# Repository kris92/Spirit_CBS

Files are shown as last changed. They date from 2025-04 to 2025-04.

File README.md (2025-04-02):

<p align="center">
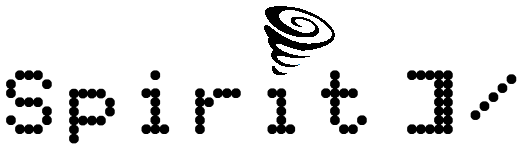
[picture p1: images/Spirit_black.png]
  
  </br>
  <font size="6">Pronounce <b>CBS</b> : <b>C</b><i>losed</i> <b>B</b><i>racket</i> <b>S</b><i>lash</i></font>
  </br>
  <font size="4">Work In Progress</font>
</p>

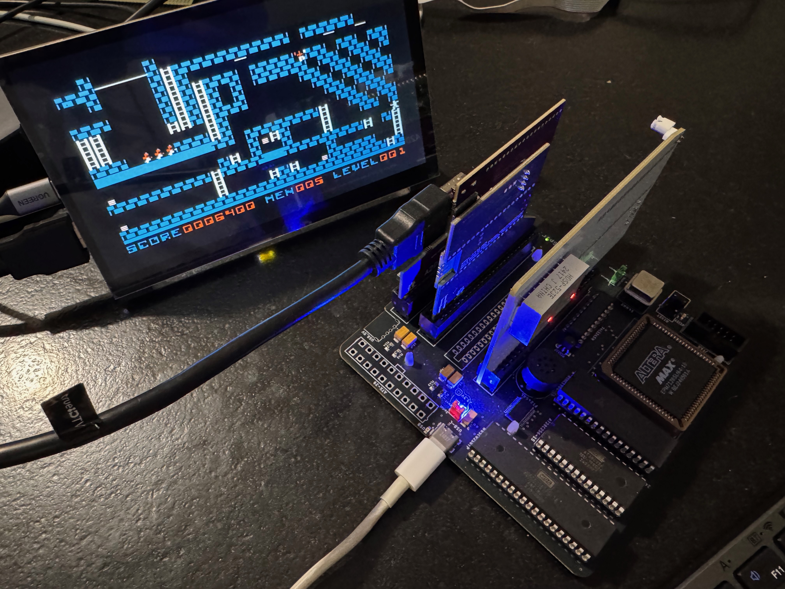
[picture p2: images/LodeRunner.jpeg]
LodeRunner


This is an attempt to build a computer somewhere in the middle of an Apple ][ and an Apple //e. So its name is Spirit ]/ (a computer with Apple II series in mind). Since the WAF (Wife Acceptance Factor) of the Apple // form factor (with disk drives and display) is somewhere near zero, I'm looking for something smaller. The first PCB iteration was half size of the System 2 with only a single slot. But one slot is really not enough.<br>
I build a serial USB probe that was really helpful for initial debuging with an interactive step mode. 
<p align="center">
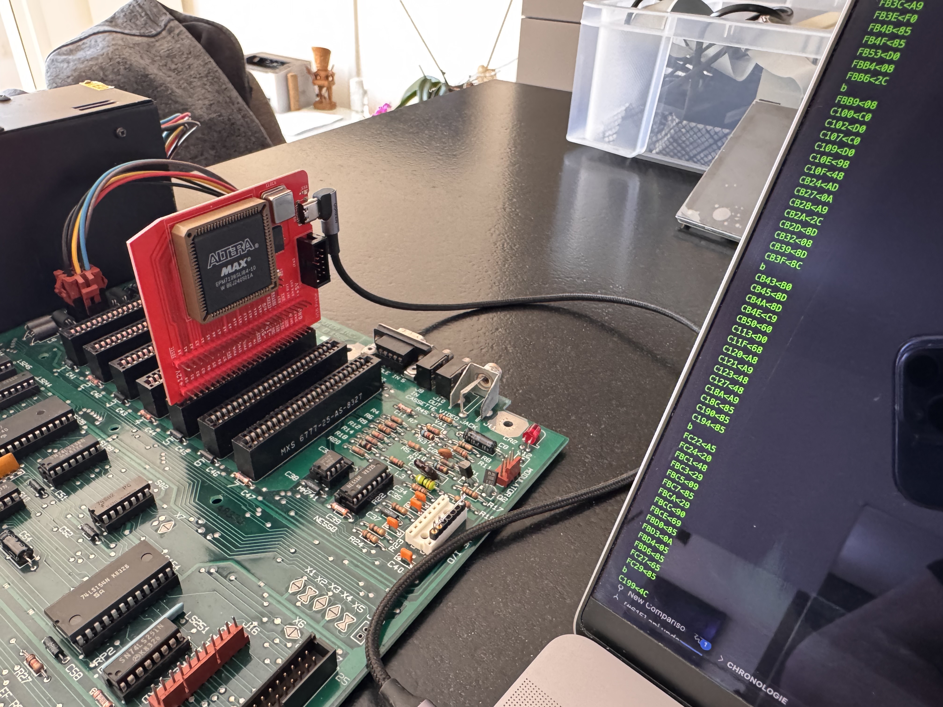
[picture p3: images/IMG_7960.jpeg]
  
  </br>
</p>

So my requirements were :

• Small (For example I choosed Pico ATX and single chips for SRAM(128K) and EEPROM).

• Compatibility with floppy drives (I ❤ how they are sounding).

• Slots. Some hardware Apple II projects exist, but I want floppies and the ability to use some of the cards from my drawers.

• Not necessary 100% compatible.

• Remove on board video to simplify design and HDMI is now possible.

• USB / RF Keyboard

• A2 Joystick

• SSC over USB (FT245) if I have enough space in the CPLD.

3 designs are planned :

• System 1 : 12cm x 12cm board for POC. 4 slots (3 + 1 since slot 0 is a ghost of slot 2 which I used for the keyboard)

• System 2 : 12cm x 14cm board with embeded USB keybpard support. 5 slots.

• System 3 : Apple //c form factor motherboard with //c keyboard support and A2DVI. 3 slots (small form factor. A2heaven like)

For this actual design, I tried to find the right balance between CPLD pins count, the fewest number of external chips and CPLD size for vhdl coding. So the actual result is not perfect but a quite good compromise in my own opinion.

Until now, Disk ][, A2Pico (SD Card), A2DVI and PRODOS-ROM cards were succesfully tested. Since native video generation is not implemented, some games may not working. I will study the possibility to emulate Blanking Softswitches and maybe vapor bits if I can find enough space in the CPLD.

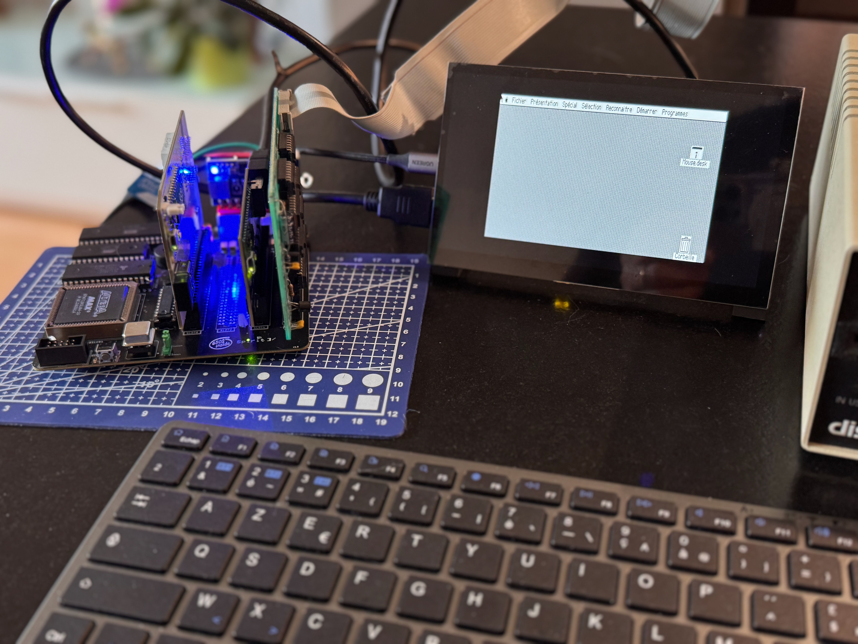
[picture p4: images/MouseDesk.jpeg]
MouseDesk loaded from a floppy


# Status
Full code for System 2 will be released as soon as a stable minimal system will be available.
| System | Date | Status |
| --- | --- | --- |
| <b>System 1</b> | 2025-03-01 | Finished.<br>Floppy, SDCard, USB Keyboard, A2DVI working.<br>Basic test of joystick interface.<br>Prodos 2.4.2 Ok.<br>Some games tested.<br>FastChip splash screen displayed then froze.<br> |
| <b>System 2</b> | 2025-03-31 | Waiting for first PCBs from JLCPCB : Motherboard, SmartPort, Disk ][, //c Keyboard interface.<br>//c keyboard RP2040 code ready. |
| <b>System 3</b> | 2025-03-31 | Initial PCB ordered for case integration test.<br>Riser card PCB ordered for slots. |

# Motherboard

The needed functions of MMU & IOU are coded inside a single CPLD (EPM7128 from Altera).

<p align="center">
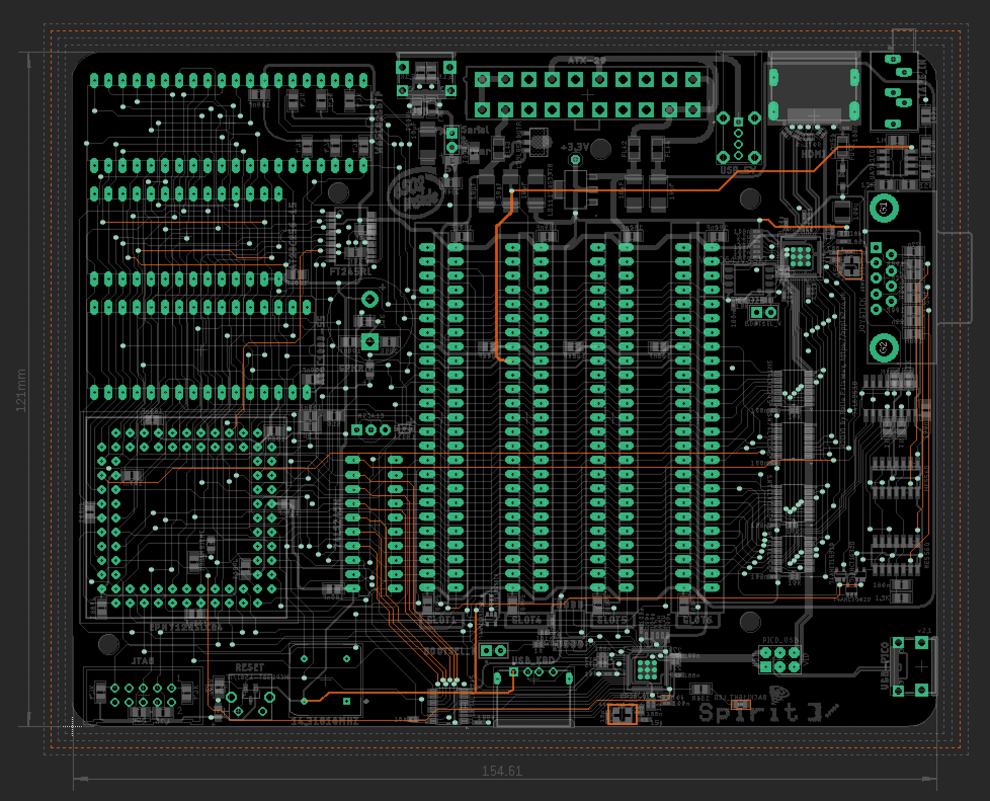
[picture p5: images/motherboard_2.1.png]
  
  </br>
</p>

## PCB
Since size matter here, all resistors, capacitors and leds are SMD. Sorry for through holes fans ;-) But I kept DIL for the main ICs (except FT245).
System 1 & 2 boards density requires a 4 layers design. System will be a classical 2 layers design.

## CPLD vhdl code
I choosed to start from [Apple-II_MiSTer](https://github.com/MiSTer-devel/Apple-II_MiSTer) implementation. Then I made modifications for real hardware interfacing. Finally the vhdl code is quite small.

## USB
The FT245RL is chip was used for initial debugging. When the vhdl code began to be too big, I've build a separate card to do 6502 buses debugging over an USB link. I'm waiting for the next version of the motherboard to check if an I can use the FT245 chip to emulate an onboard Super Serial Card. If SSC can not fit in the CPLD, FT245 may be removed from future designs.

USB Keyboard support is mentionned below.

# Keyboard card

The RP2040 act as the 3660 Pro encoder from the original Apple II. So it generates AKD and KSTRB signals and 7bits ASCII. The pico chip generates the autorepeat features. This is one more thing not to be implemented in the CPLD. The next card release will implement the CTRL-ALT-RESET combination. 2 flavors : USB and //c keyboard.

## build Pico code

```bash
mkdir pico/keyboard/build
cd pico/keyboard/build
cmake ..
git submodule update --init --recursive
make
```

Drag and drop file SpiritKBDBoard.uf2 to the pico

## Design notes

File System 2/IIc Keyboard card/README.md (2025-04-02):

Warning, this board will not work on a real Apple II system. Missing AKD, KSTRB and KBD signals are routed to available pins of the Spirit system slot 1.

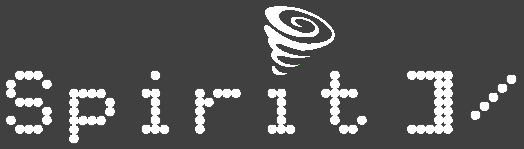
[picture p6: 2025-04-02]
images/Spirit_white.png

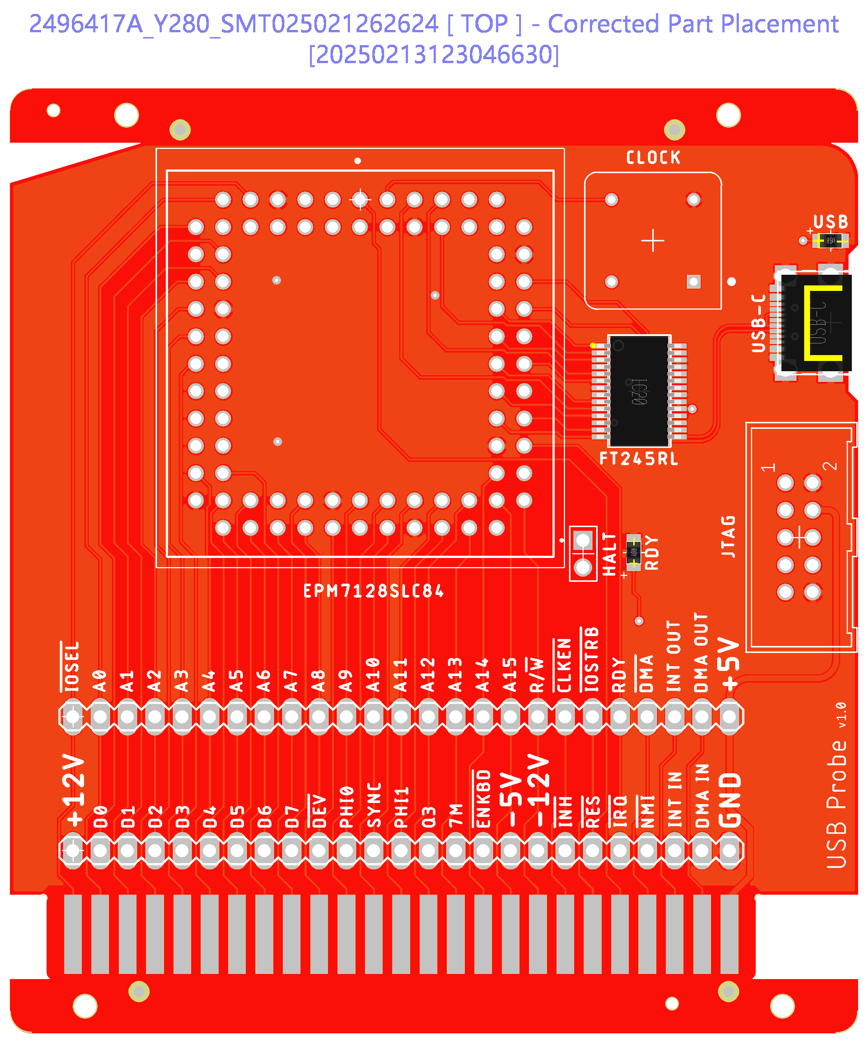
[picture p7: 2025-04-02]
SerialUSB Probe/pcb/probe_USB_1.0.png

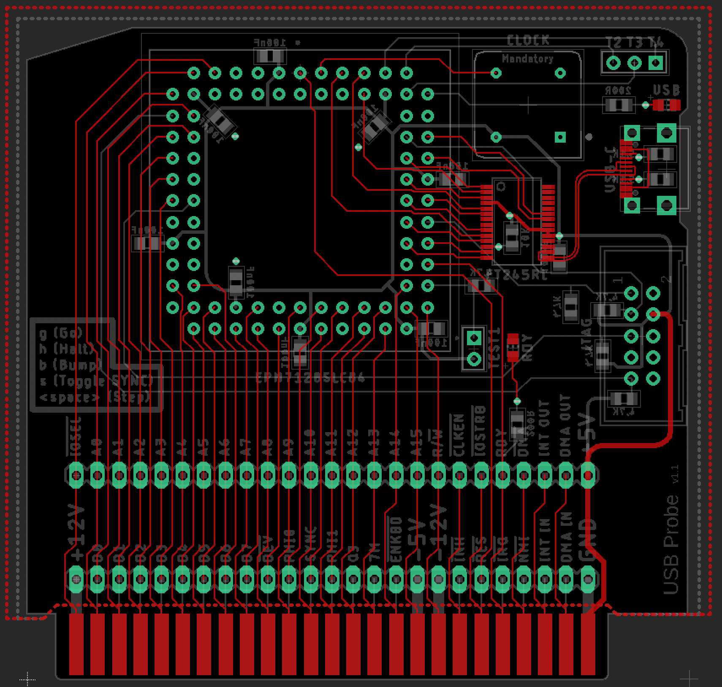
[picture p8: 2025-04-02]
SerialUSB Probe/pcb/probe_USB_1.1.png

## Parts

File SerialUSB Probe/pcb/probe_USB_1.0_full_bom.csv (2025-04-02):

Comment | Designator | Footprint | LCSC Part #
217179-0001 | USB-C | GCT_USB4105-GF-A | C3197684
APTD2012LCGCK | USB | CHIP-LED0805 | C5366381
APTD2012LSURCK | RDY | CHIP-LED0805 | C5366382
FT245RL | IC20 | SSOP28DB | C12633
4.7K | R1 R51 R52 R53 R54 | R0805 | C17673
5.1K | R20 R22 | R0805 | C27834
10K | R23 | R0805 | C17414
100nF | C25 C51 C52 C53 C54 C55 C56 C57 C58 | C0805 | C49678
200R | R2 R63 | R0805 | C17540

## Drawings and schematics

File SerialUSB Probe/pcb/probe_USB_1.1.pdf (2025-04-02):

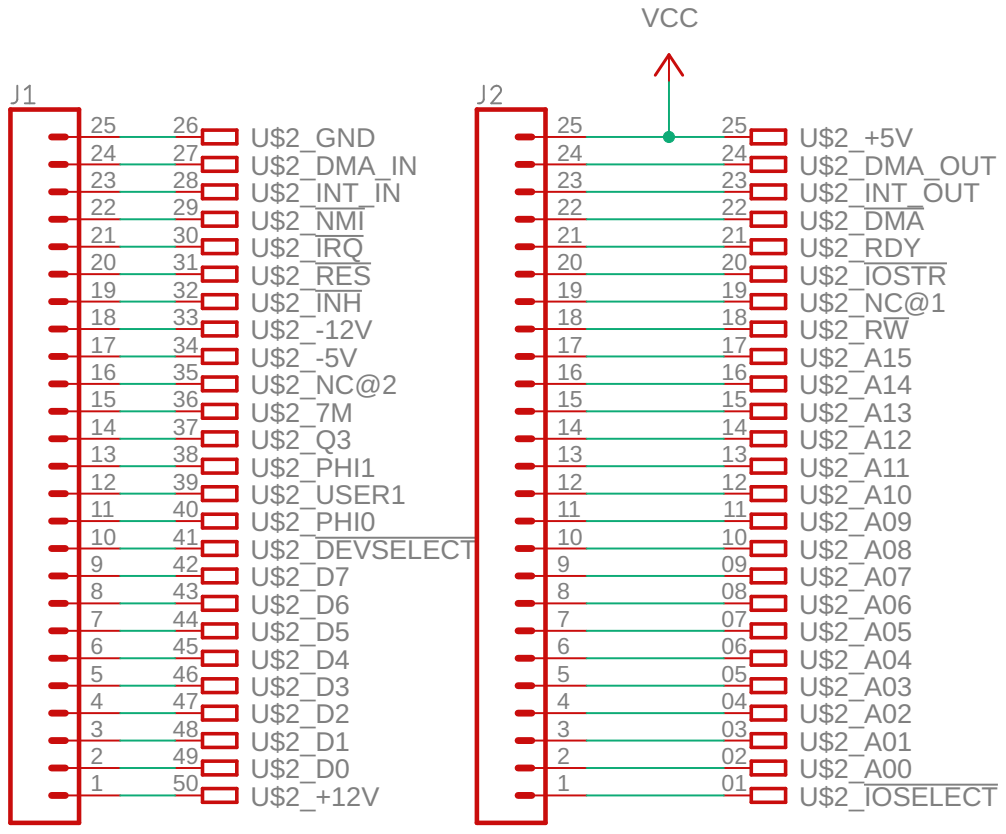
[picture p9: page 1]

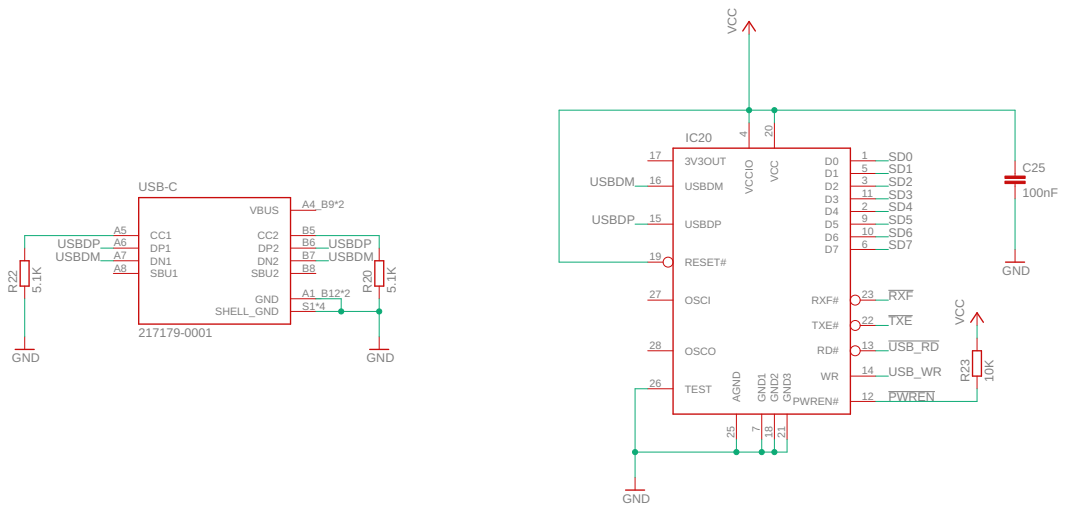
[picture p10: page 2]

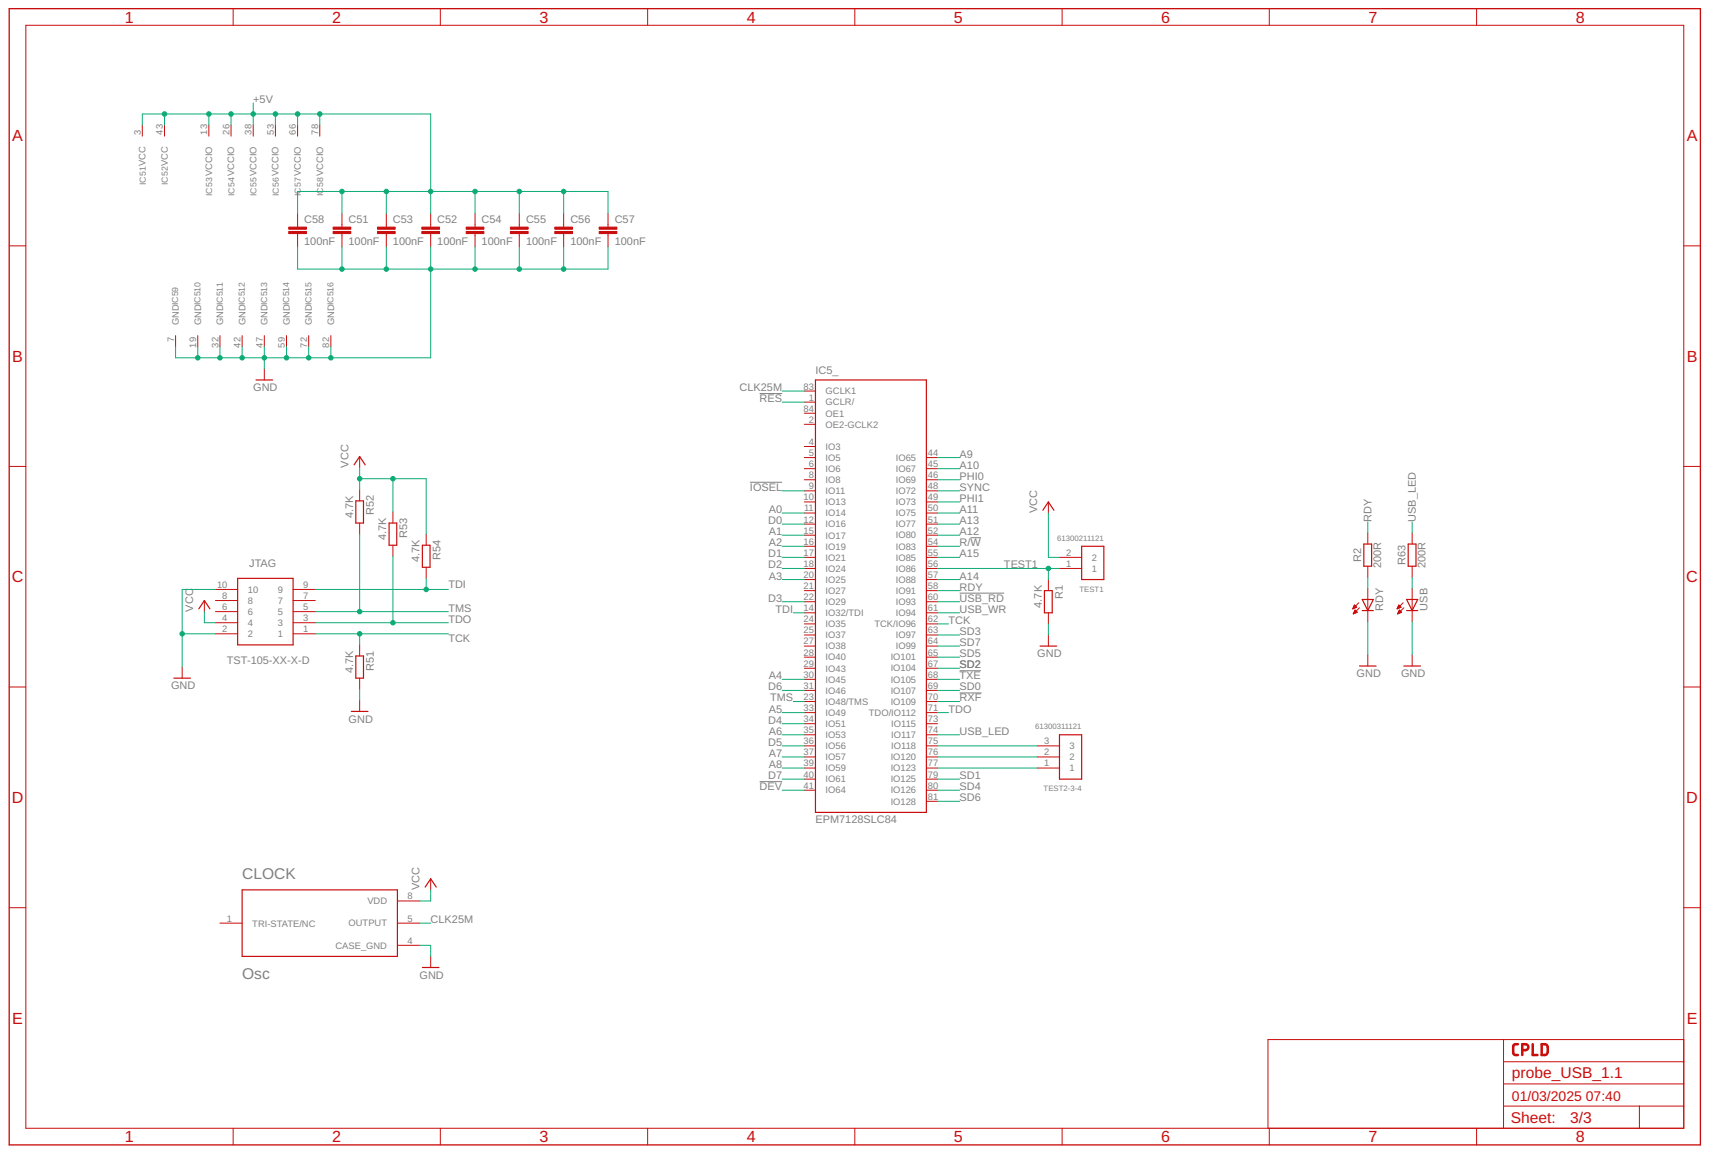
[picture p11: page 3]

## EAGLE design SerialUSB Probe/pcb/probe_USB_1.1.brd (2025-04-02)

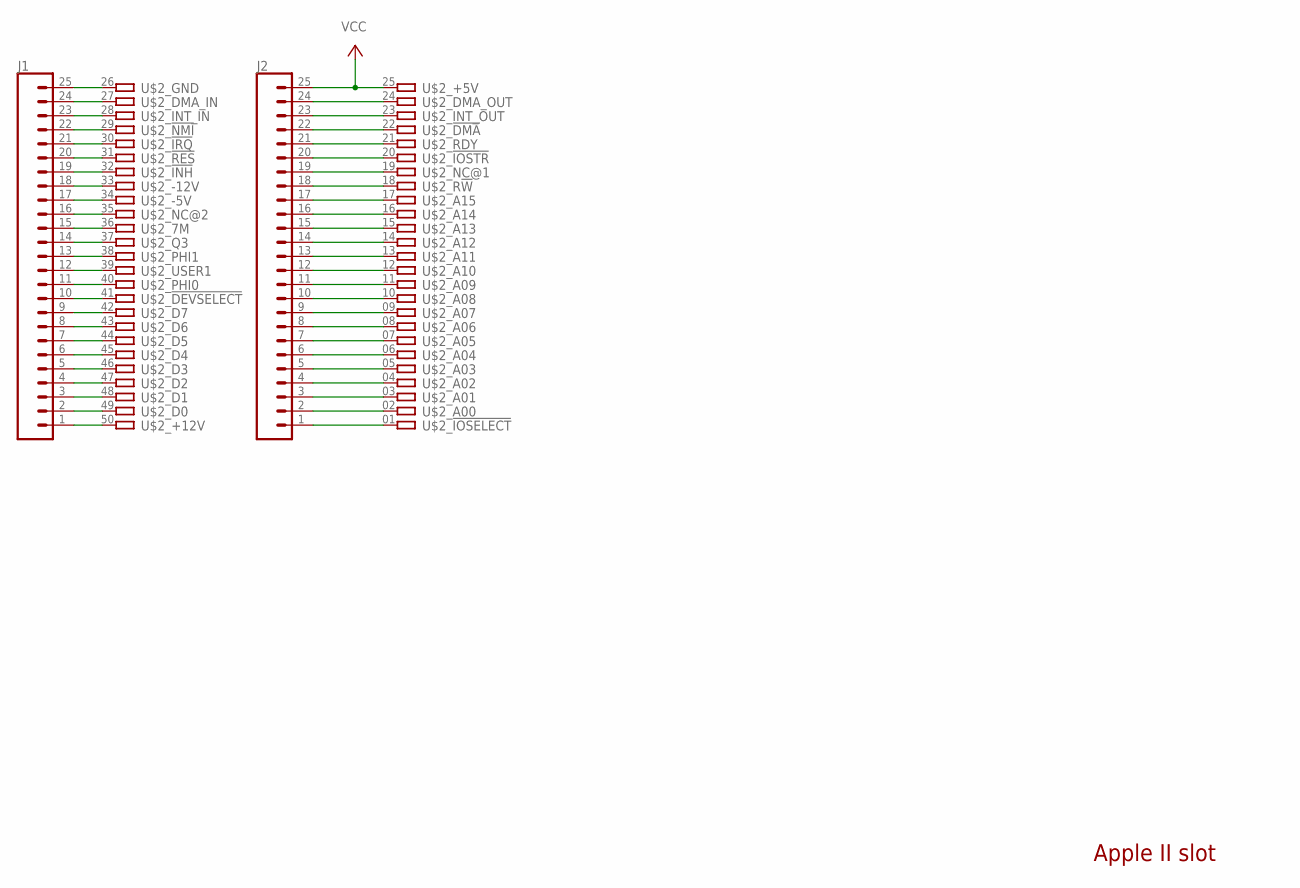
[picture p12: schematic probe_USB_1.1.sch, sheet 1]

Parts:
J1, J2: CONN_25PTH_LONGPADS; 1X25_LONGPAD
U$2: A2-50PINSLOT1-3; A2-50PIN-SL1-3

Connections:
!CLKEN: J2.19, U$2.19
!DEV: J1.10, U$2.41; also elsewhere on the board
!I/OSTROBE: J2.20, U$2.20
!IOSEL: J2.1, U$2.01; also elsewhere on the board
!KBD: J1.16, U$2.35
!RES: J1.20, U$2.31; also elsewhere on the board
+5V: J2.25, U$2.25; also elsewhere on the board
A0: J2.2, U$2.02; also elsewhere on the board
A1: J2.3, U$2.03; also elsewhere on the board
A2: J2.4, U$2.04; also elsewhere on the board
A3: J2.5, U$2.05; also elsewhere on the board
A4: J2.6, U$2.06; also elsewhere on the board
A5: J2.7, U$2.07; also elsewhere on the board
A6: J2.8, U$2.08; also elsewhere on the board
A7: J2.9, U$2.09; also elsewhere on the board
A8: J2.10, U$2.10; also elsewhere on the board
A9: J2.11, U$2.11; also elsewhere on the board
A10: J2.12, U$2.12; also elsewhere on the board
A11: J2.13, U$2.13; also elsewhere on the board
A12: J2.14, U$2.14; also elsewhere on the board
A13: J2.15, U$2.15; also elsewhere on the board
A14: J2.16, U$2.16; also elsewhere on the board
A15: J2.17, U$2.17; also elsewhere on the board
D0: J1.2, U$2.49; also elsewhere on the board
D1: J1.3, U$2.48; also elsewhere on the board
D2: J1.4, U$2.47; also elsewhere on the board
D3: J1.5, U$2.46; also elsewhere on the board
D4: J1.6, U$2.45; also elsewhere on the board
D5: J1.7, U$2.44; also elsewhere on the board
D6: J1.8, U$2.43; also elsewhere on the board
D7: J1.9, U$2.42; also elsewhere on the board
DMA_IN: J1.24, U$2.27
GND: J1.25, U$2.26; also elsewhere on the board
INT_IN: J1.23, U$2.28
unnamed: J1.22, U$2.29
unnamed: J2.22, U$2.22
unnamed: J2.23, U$2.23
unnamed: J2.24, U$2.24
unnamed: J1.21, U$2.30
unnamed: J1.19, U$2.32
unnamed: J1.18, U$2.33
unnamed: J1.17, U$2.34
unnamed: J1.15, U$2.36
unnamed: J1.14, U$2.37
unnamed: J1.1, U$2.50
PHI0: J1.11, U$2.40; also elsewhere on the board
PHI1: J1.13, U$2.38; also elsewhere on the board
R/!W: J2.18, U$2.18; also elsewhere on the board
RDY: J2.21, U$2.21; also elsewhere on the board
SYNC: J1.12, U$2.39; also elsewhere on the board

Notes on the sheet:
Apple II slot

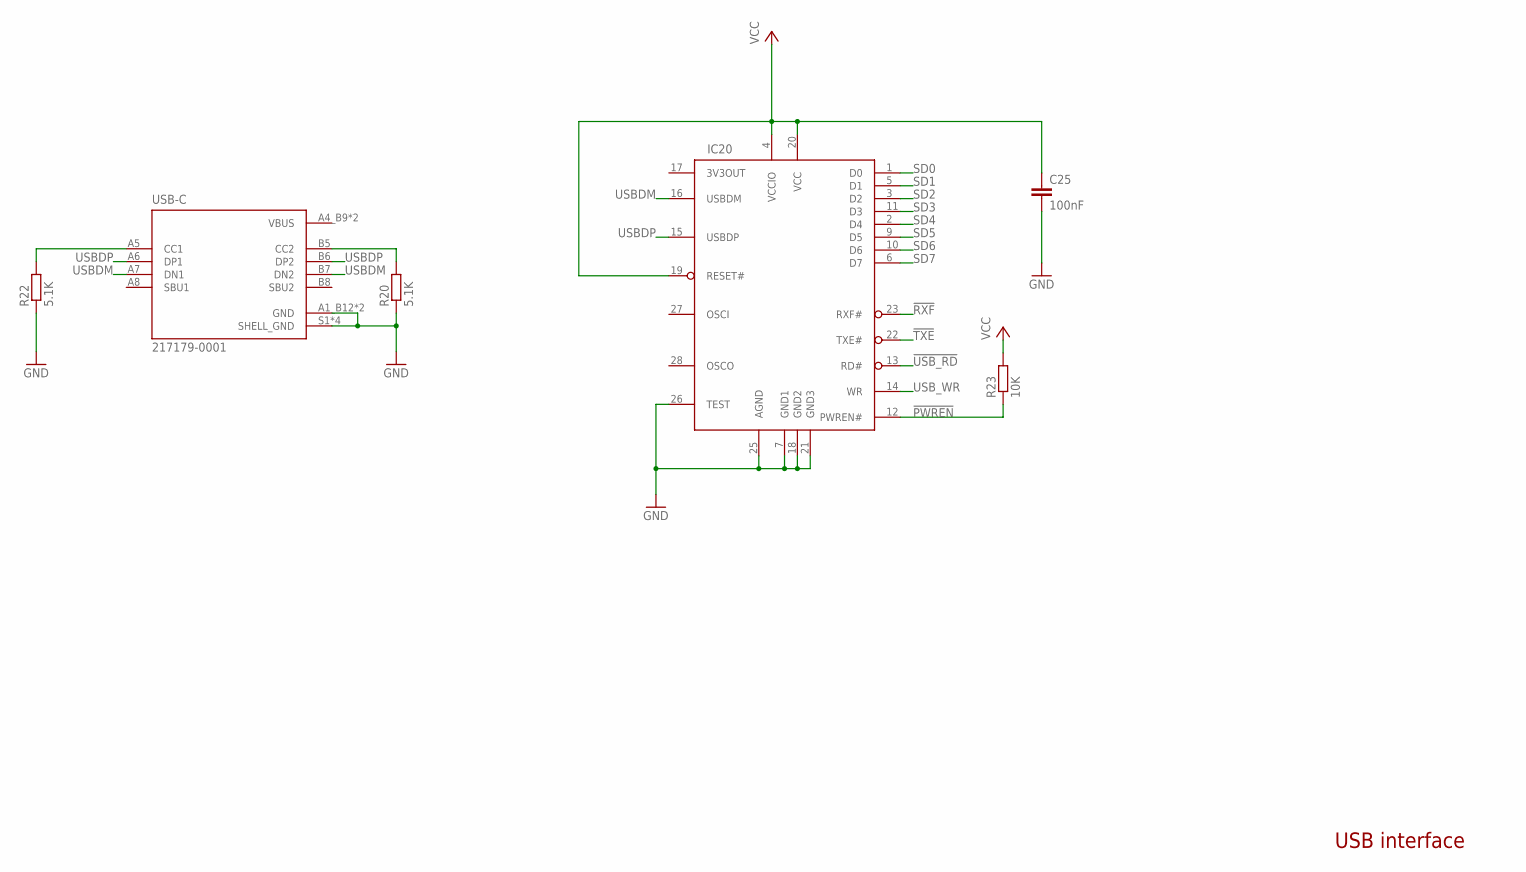
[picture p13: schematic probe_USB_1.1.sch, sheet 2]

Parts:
C25: 100nF; C0805
IC20: FT245RL; SSOP28DB
R20, R22: 5.1K; R0805
R23: 10K; R0805
USB-C: 217179-0001; GCT_USB4105-GF-A

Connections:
!PWREN: IC20.12 (PWREN#), R23.1
!RXF: IC20.23 (RXF#); also elsewhere on the board
!TXE: IC20.22 (TXE#); also elsewhere on the board
!USB_RD: IC20.13 (RD#); also elsewhere on the board
+5V: C25.1, IC20.4 (VCCIO), IC20.19 (RESET#), IC20.20 (VCC), R23.2; also elsewhere on the board
GND: C25.2, IC20.7 (GND1), IC20.18 (GND2), IC20.21 (GND3), IC20.25 (AGND), IC20.26 (TEST), R20.1, R22.1, USB-C.A1_B12 (GND), USB-C.B1_A12 (GND), USB-C.S1 (SHELL_GND), USB-C.S2 (SHELL_GND), USB-C.S3 (SHELL_GND), USB-C.S4 (SHELL_GND); also elsewhere on the board
unnamed: R22.2, USB-C.A5 (CC1)
unnamed: R20.2, USB-C.B5 (CC2)
SD0: IC20.1 (D0); also elsewhere on the board
SD1: IC20.5 (D1); also elsewhere on the board
SD2: IC20.3 (D2); also elsewhere on the board
SD3: IC20.11 (D3); also elsewhere on the board
SD4: IC20.2 (D4); also elsewhere on the board
SD5: IC20.9 (D5); also elsewhere on the board
SD6: IC20.10 (D6); also elsewhere on the board
SD7: IC20.6 (D7); also elsewhere on the board
USBDM: IC20.16 (USBDM), USB-C.A7 (DN1), USB-C.B7 (DN2)
USBDP: IC20.15 (USBDP), USB-C.A6 (DP1), USB-C.B6 (DP2)
USB_WR: IC20.14 (WR); also elsewhere on the board
VBUS: USB-C.A4_B9 (VBUS), USB-C.B4_A9 (VBUS)

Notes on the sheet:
USB interface

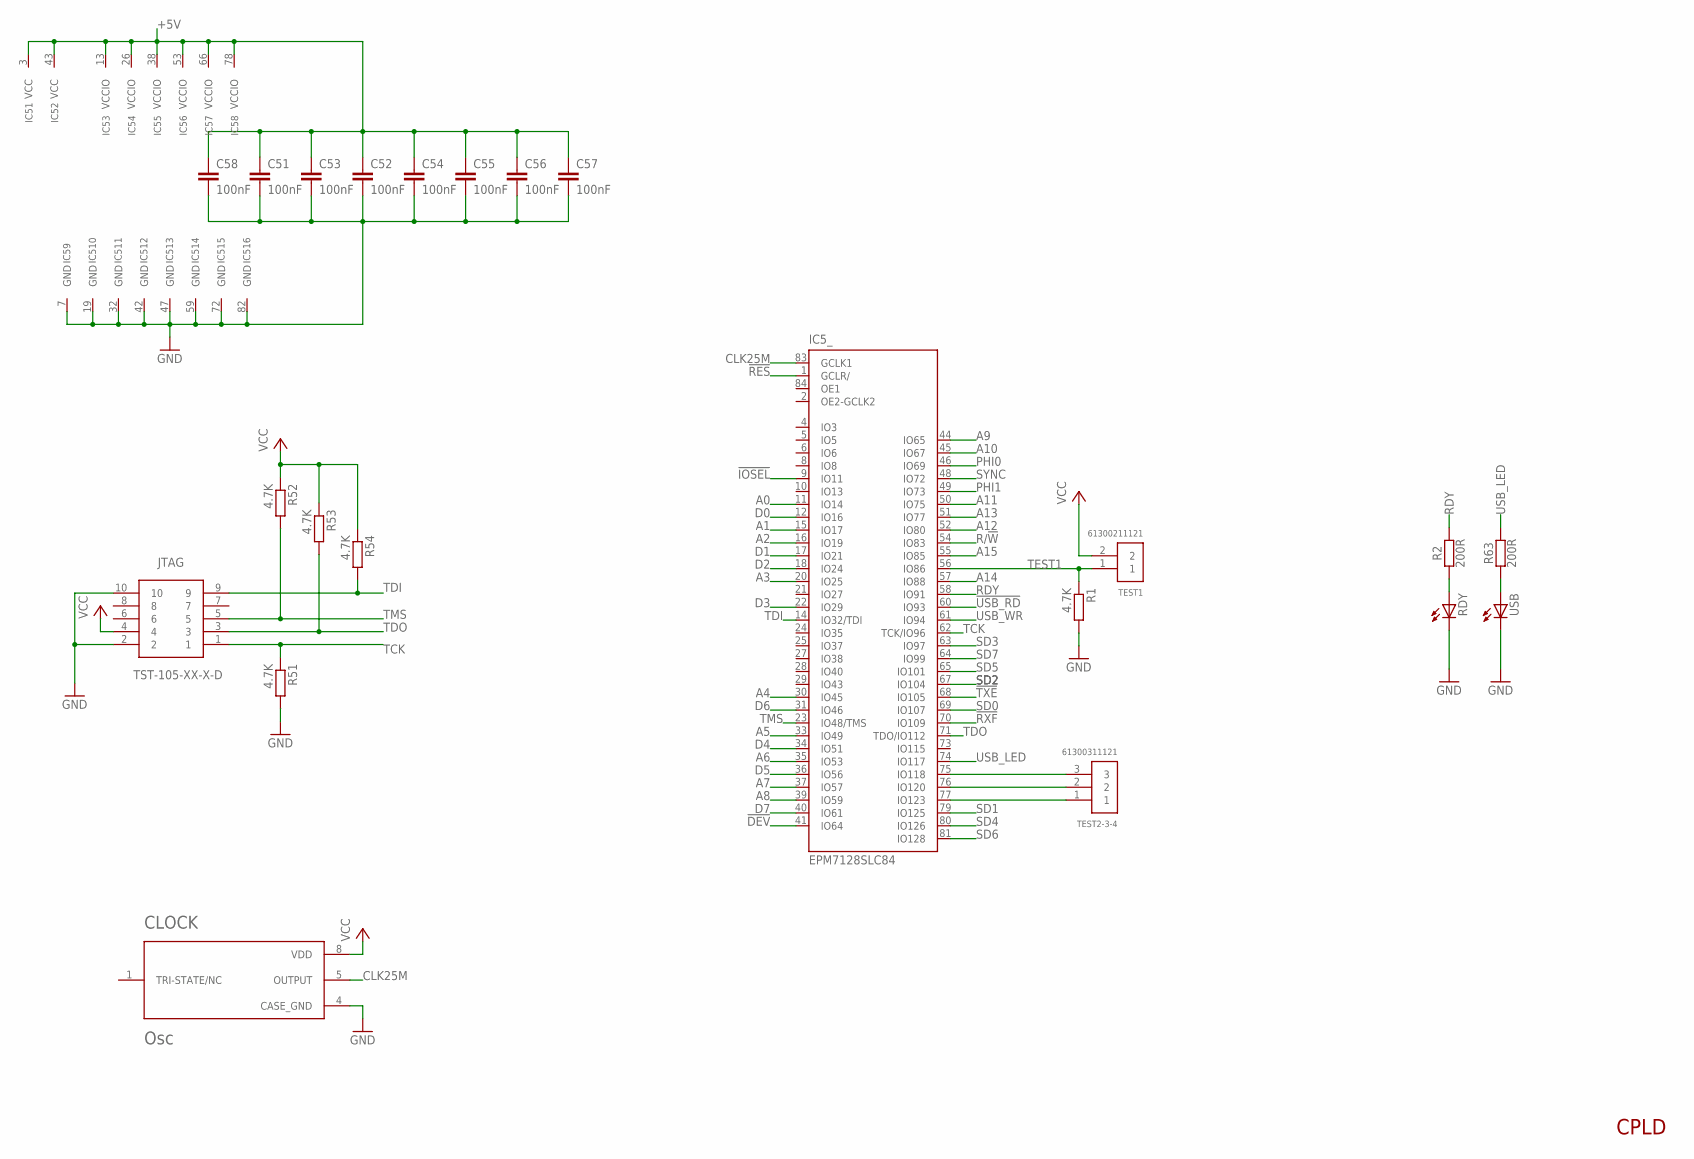
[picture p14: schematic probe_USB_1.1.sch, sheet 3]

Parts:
C51, C52, C53, C54, C55, C56, C57, C58: 100nF; C0805
CLOCK: Osc; OSC762W46P254L1270H639Q8
IC5: EPM7128SLC84; 9404408424000000
JTAG: TST-105-XX-X-D
R1, R51, R52, R53, R54: 4.7K; R0805
R2, R63: 200R; R0805
RDY: APTD2012LSURCK; CHIP-LED0805
TEST1: 61300211121
TEST2-3-4: 61300311121
USB: APTD2012LCGCK; CHIP-LED0805

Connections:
!DEV: IC5.41 (IO64); also elsewhere on the board
!IOSEL: IC5.9 (IO11); also elsewhere on the board
!RES: IC5.1 (GCLR/); also elsewhere on the board
!RXF: IC5.70 (IO109); also elsewhere on the board
!TXE: IC5.68 (IO105); also elsewhere on the board
!USB_RD: IC5.60 (IO93); also elsewhere on the board
+5V: C51.1, C52.1, C53.1, C54.1, C55.1, C56.1, C57.1, C58.1, CLOCK.8 (VDD), IC5.3 (VCC), IC5.13 (VCCIO), IC5.26 (VCCIO), IC5.38 (VCCIO), IC5.43 (VCC), IC5.53 (VCCIO), IC5.66 (VCCIO), IC5.78 (VCCIO), JTAG.4, R52.1, R53.1, R54.1, TEST1.2; also elsewhere on the board
A0: IC5.11 (IO14); also elsewhere on the board
A1: IC5.15 (IO17); also elsewhere on the board
A2: IC5.16 (IO19); also elsewhere on the board
A3: IC5.20 (IO25); also elsewhere on the board
A4: IC5.30 (IO45); also elsewhere on the board
A5: IC5.33 (IO49); also elsewhere on the board
A6: IC5.35 (IO53); also elsewhere on the board
A7: IC5.37 (IO57); also elsewhere on the board
A8: IC5.39 (IO59); also elsewhere on the board
A9: IC5.44 (IO65); also elsewhere on the board
A10: IC5.45 (IO67); also elsewhere on the board
A11: IC5.50 (IO75); also elsewhere on the board
A12: IC5.52 (IO80); also elsewhere on the board
A13: IC5.51 (IO77); also elsewhere on the board
A14: IC5.57 (IO88); also elsewhere on the board
A15: IC5.55 (IO85); also elsewhere on the board
CLK25M: CLOCK.5 (OUTPUT), IC5.83 (GCLK1)
D0: IC5.12 (IO16); also elsewhere on the board
D1: IC5.17 (IO21); also elsewhere on the board
D2: IC5.18 (IO24); also elsewhere on the board
D3: IC5.22 (IO29); also elsewhere on the board
D4: IC5.34 (IO51); also elsewhere on the board
D5: IC5.36 (IO56); also elsewhere on the board
D6: IC5.31 (IO46); also elsewhere on the board
D7: IC5.40 (IO61); also elsewhere on the board
GND: C51.2, C52.2, C53.2, C54.2, C55.2, C56.2, C57.2, C58.2, CLOCK.4 (CASE_GND), IC5.7 (GND), IC5.19 (GND), IC5.32 (GND), IC5.42 (GND), IC5.47 (GND), IC5.59 (GND), IC5.72 (GND), IC5.82 (GND), JTAG.2, JTAG.10, R1.2, R51.2, RDY.C, USB.C; also elsewhere on the board
unnamed: IC5.75 (IO118), TEST2-3-4.3
unnamed: R2.1, RDY.A
unnamed: IC5.76 (IO120), TEST2-3-4.2
unnamed: IC5.77 (IO123), TEST2-3-4.1
unnamed: R63.1, USB.A
PHI0: IC5.46 (IO69); also elsewhere on the board
PHI1: IC5.49 (IO73); also elsewhere on the board
R/!W: IC5.54 (IO83); also elsewhere on the board
RDY: IC5.58 (IO91), R2.2; also elsewhere on the board
SD0: IC5.69 (IO107); also elsewhere on the board
SD1: IC5.79 (IO125); also elsewhere on the board
SD2: IC5.67 (IO104); also elsewhere on the board
SD3: IC5.63 (IO97); also elsewhere on the board
SD4: IC5.80 (IO126); also elsewhere on the board
SD5: IC5.65 (IO101); also elsewhere on the board
SD6: IC5.81 (IO128); also elsewhere on the board
SD7: IC5.64 (IO99); also elsewhere on the board
SYNC: IC5.48 (IO72); also elsewhere on the board
TCK: IC5.62 (TCK/IO96), JTAG.1, R51.1
TDI: IC5.14 (IO32/TDI), JTAG.9, R54.2
TDO: IC5.71 (TDO/IO112), JTAG.3, R53.2
TEST1: IC5.56 (IO86), R1.1, TEST1.1
TMS: IC5.23 (IO48/TMS), JTAG.5, R52.2
USB_LED: IC5.74 (IO117), R63.2
USB_WR: IC5.61 (IO94); also elsewhere on the board

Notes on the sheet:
CPLD

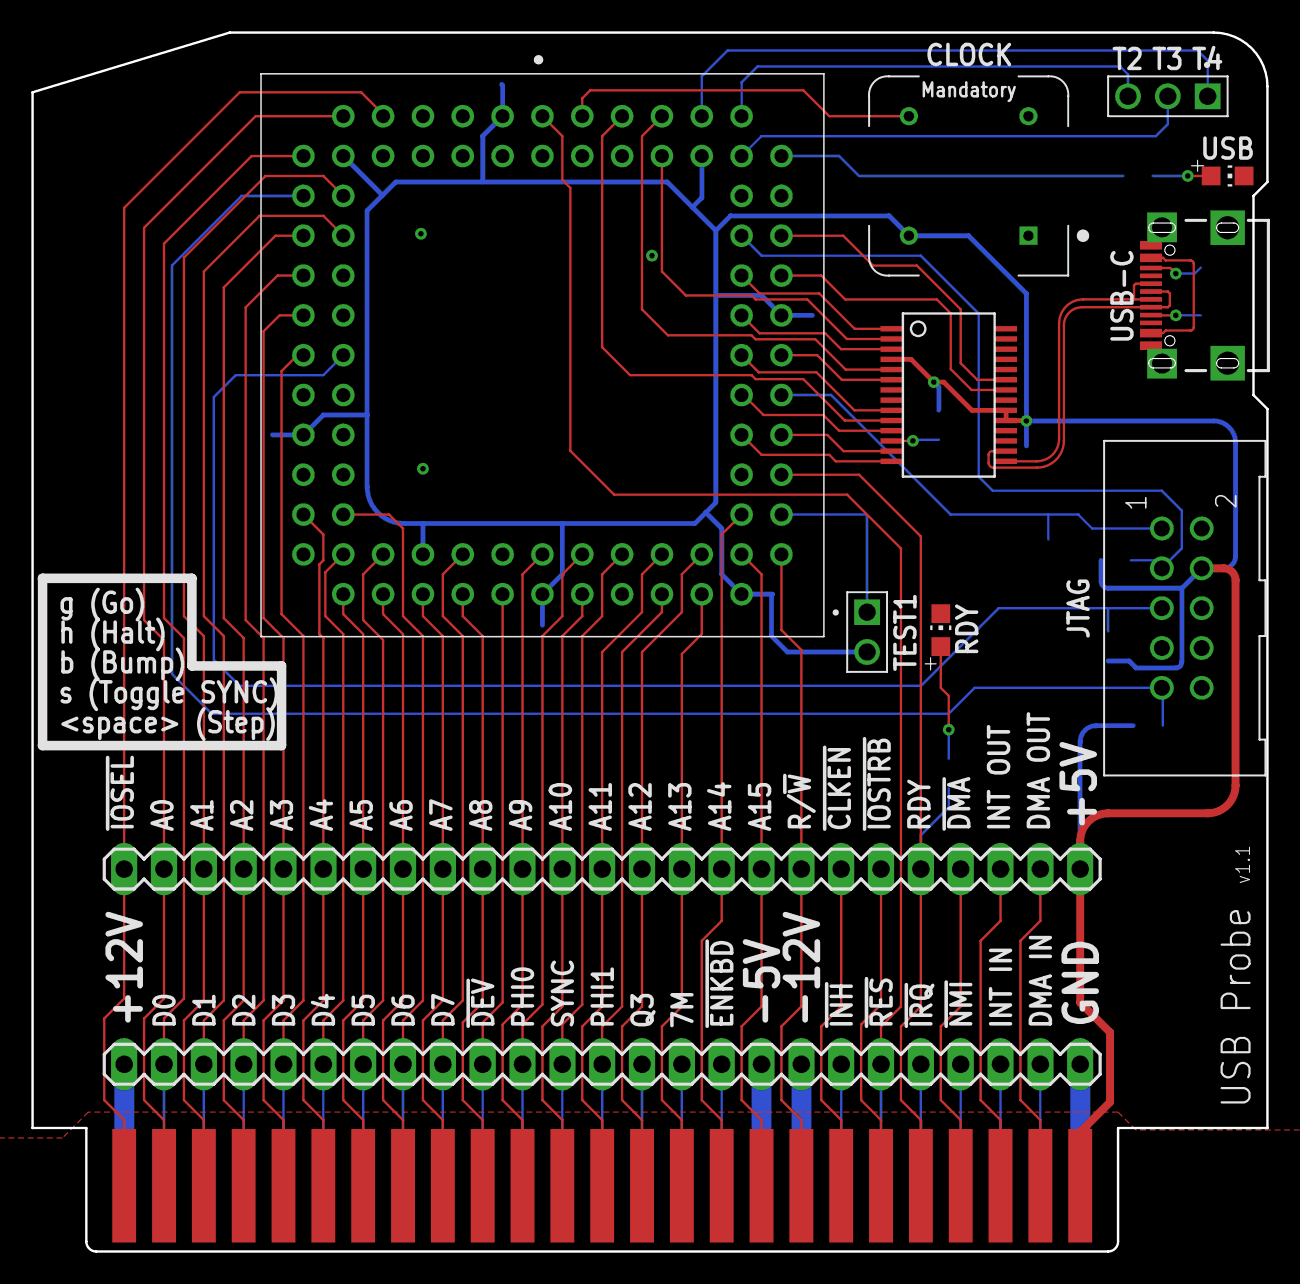
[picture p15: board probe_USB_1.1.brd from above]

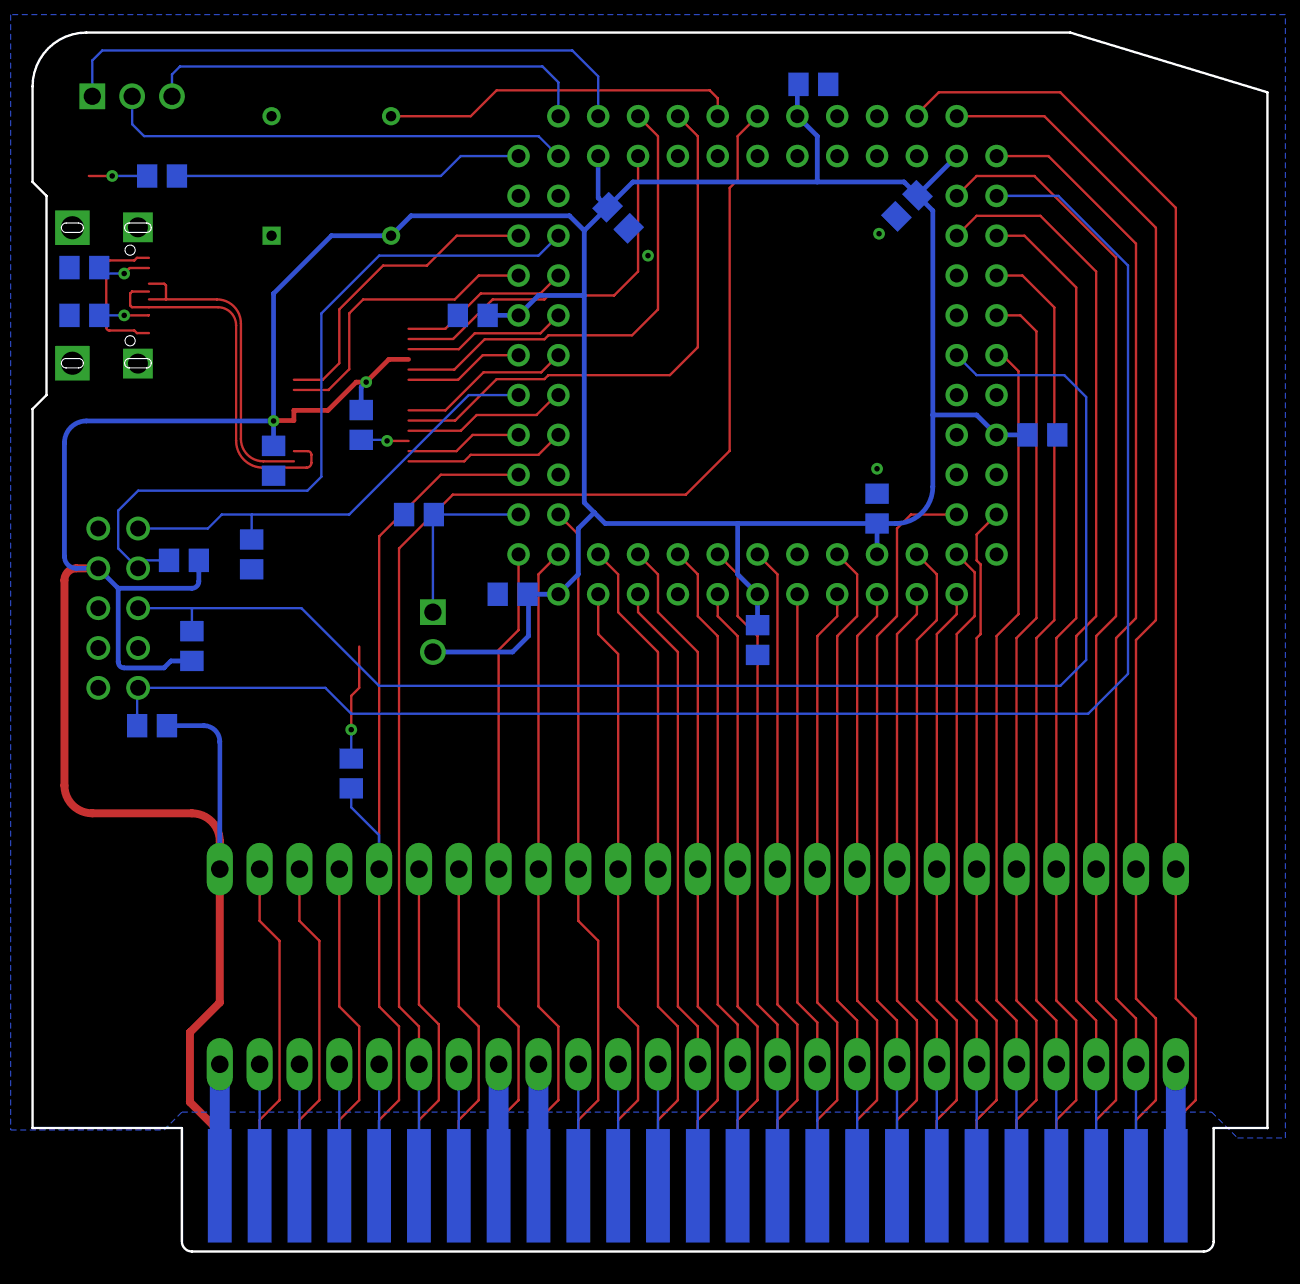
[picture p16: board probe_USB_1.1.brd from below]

Board: 2 copper layers, 78.7 x 77.7 mm, 31 parts (19 on the bottom side), 80 nets.

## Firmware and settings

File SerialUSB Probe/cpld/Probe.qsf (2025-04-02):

# -------------------------------------------------------------------------- #
#
# Copyright (C) 1991-2013 Altera Corporation
# Your use of Altera Corporation's design tools, logic functions 
# and other software and tools, and its AMPP partner logic 
# functions, and any output files from any of the foregoing 
# (including device programming or simulation files), and any 
# associated documentation or information are expressly subject 
# to the terms and conditions of the Altera Program License 
# Subscription Agreement, Altera MegaCore Function License 
# Agreement, or other applicable license agreement, including, 
# without limitation, that your use is for the sole purpose of 
# programming logic devices manufactured by Altera and sold by 
# Altera or its authorized distributors.  Please refer to the 
# applicable agreement for further details.
#
# -------------------------------------------------------------------------- #
#
# Quartus II 64-Bit
# Version 13.0.1 Build 232 06/12/2013 Service Pack 1 SJ Web Edition
# Date created = 22:29:05  February 16, 2025
#
# -------------------------------------------------------------------------- #
#
# Notes:
#
# 1) The default values for assignments are stored in the file:
#		Echo_assignment_defaults.qdf
#    If this file doesn't exist, see file:
#		assignment_defaults.qdf
#
# 2) Altera recommends that you do not modify this file. This
#    file is updated automatically by the Quartus II software
#    and any changes you make may be lost or overwritten.
#
# -------------------------------------------------------------------------- #


set_global_assignment -name FAMILY MAX7000S
set_global_assignment -name DEVICE "EPM7128SLC84-10"
set_global_assignment -name TOP_LEVEL_ENTITY Probe
set_global_assignment -name ORIGINAL_QUARTUS_VERSION "13.0 SP1"
set_global_assignment -name PROJECT_CREATION_TIME_DATE "22:29:05  FEBRUARY 16, 2025"
set_global_assignment -name LAST_QUARTUS_VERSION "13.0 SP1"
set_global_assignment -name PROJECT_OUTPUT_DIRECTORY output_files
set_global_assignment -name ERROR_CHECK_FREQUENCY_DIVISOR "-1"
set_global_assignment -name MIN_CORE_JUNCTION_TEMP 0
set_global_assignment -name MAX_CORE_JUNCTION_TEMP 85
set_global_assignment -name NUM_PARALLEL_PROCESSORS 1
set_global_assignment -name ALLOW_POWER_UP_DONT_CARE OFF
set_global_assignment -name RESERVE_ALL_UNUSED_PINS_NO_OUTPUT_GND "AS INPUT TRI-STATED"

#set_location_assignment PIN_83 -to CLK12M
set_location_assignment PIN_46 -to PHI_0

#set_location_assignment PIN_56 -to TEST1
#set_location_assignment PIN_75 -to TEST2
#set_location_assignment PIN_76 -to TEST3
#set_location_assignment PIN_77 -to TEST4

# Interrupts
set_location_assignment PIN_1 -to nRESET

# CPU
set_location_assignment PIN_54 -to RnW
set_location_assignment PIN_58 -to RDY
set_location_assignment PIN_48 -to SYNC

# Slot
#set_location_assignment PIN_9 -to nIOSEL
#set_location_assignment PIN_41 -to nDEV
#set_location_assignment PIN_9 -to nIO_STROBE

# CPU addresses bus
set_location_assignment PIN_11 -to A[0]
set_location_assignment PIN_15 -to A[1]
set_location_assignment PIN_16 -to A[2]
set_location_assignment PIN_20 -to A[3]
set_location_assignment PIN_30 -to A[4]
set_location_assignment PIN_33 -to A[5]
set_location_assignment PIN_35 -to A[6]
set_location_assignment PIN_37 -to A[7]
set_location_assignment PIN_39 -to A[8]
set_location_assignment PIN_44 -to A[9]
set_location_assignment PIN_45 -to A[10]
set_location_assignment PIN_50 -to A[11]
set_location_assignment PIN_52 -to A[12]
set_location_assignment PIN_51 -to A[13]
set_location_assignment PIN_57 -to A[14]
set_location_assignment PIN_55 -to A[15]

# Data bus
set_location_assignment PIN_12 -to D[0]
set_location_assignment PIN_17 -to D[1]
set_location_assignment PIN_18 -to D[2]
set_location_assignment PIN_22 -to D[3]
set_location_assignment PIN_34 -to D[4]
set_location_assignment PIN_36 -to D[5]
set_location_assignment PIN_31 -to D[6]
set_location_assignment PIN_40 -to D[7]

# FT245
set_location_assignment PIN_60 -to nUSB_RD
set_location_assignment PIN_61 -to USB_WR
set_location_assignment PIN_70 -to nRXF
set_location_assignment PIN_68 -to nTXE
set_location_assignment PIN_69 -to SD[0]
set_location_assignment PIN_79 -to SD[1]
set_location_assignment PIN_67 -to SD[2]
set_location_assignment PIN_63 -to SD[3]
set_location_assignment PIN_80 -to SD[4]
set_location_assignment PIN_65 -to SD[5]
set_location_assignment PIN_81 -to SD[6]
set_location_assignment PIN_64 -to SD[7]
set_location_assignment PIN_74 -to USB_LED

set_global_assignment -name SDC_FILE Probe.sdc
set_global_assignment -name VHDL_FILE Probe.vhdl
set_global_assignment -name VHDL_FILE DebugConsole.vhdl
set_global_assignment -name MAX7000_OPTIMIZATION_TECHNIQUE AREA
set_global_assignment -name MAX7000_DEVICE_IO_STANDARD "3.3-V LVTTL"
set_global_assignment -name USE_CONFIGURATION_DEVICE ON

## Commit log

2025-04-02 Probe image
2025-04-02 Serial USB Probe
    [probe_USB_1.0_full_bom.csv, probe_USB_1.1.brd, probe_USB_1.1.sch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]

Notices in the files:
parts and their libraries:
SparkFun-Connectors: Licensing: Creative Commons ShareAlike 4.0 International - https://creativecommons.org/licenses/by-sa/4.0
